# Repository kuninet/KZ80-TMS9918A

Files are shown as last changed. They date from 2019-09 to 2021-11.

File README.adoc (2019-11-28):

== KZ80シリーズ TMS9918A ビデオボード

=== 概要
* SBC8080バスにつながるTMS9918Aビデオボードのプロジェクトです。
* 本ボードの詳しい説明は以下のwikiページをご覧ください。
** https://github.com/kuninet/KZ80-TMS9918A/wiki

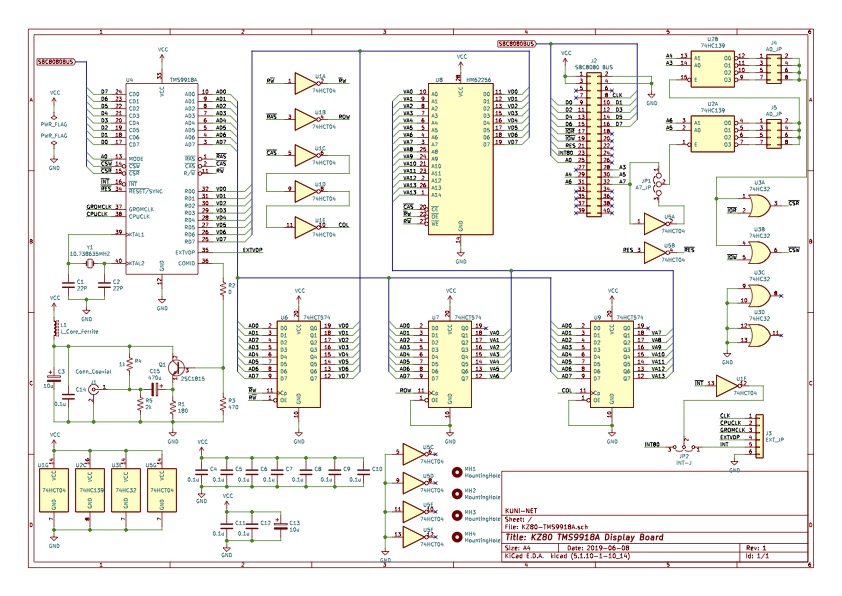
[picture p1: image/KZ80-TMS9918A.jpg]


=== ライセンス
* 本プロジェクトのデータはMITライセンスのもとで公開します。

=== 参考
* 以下のサイトの情報を参考に作成しています。ありがとうございます。
** https://github.com/jblang/TMS9918A
** https://retrobrewcomputers.org/n8vem-pbwiki-archive/0/35845334/48860720/33053543/SRAM%20Replacement%20for%20TMS99x8%20VRAM.pdf

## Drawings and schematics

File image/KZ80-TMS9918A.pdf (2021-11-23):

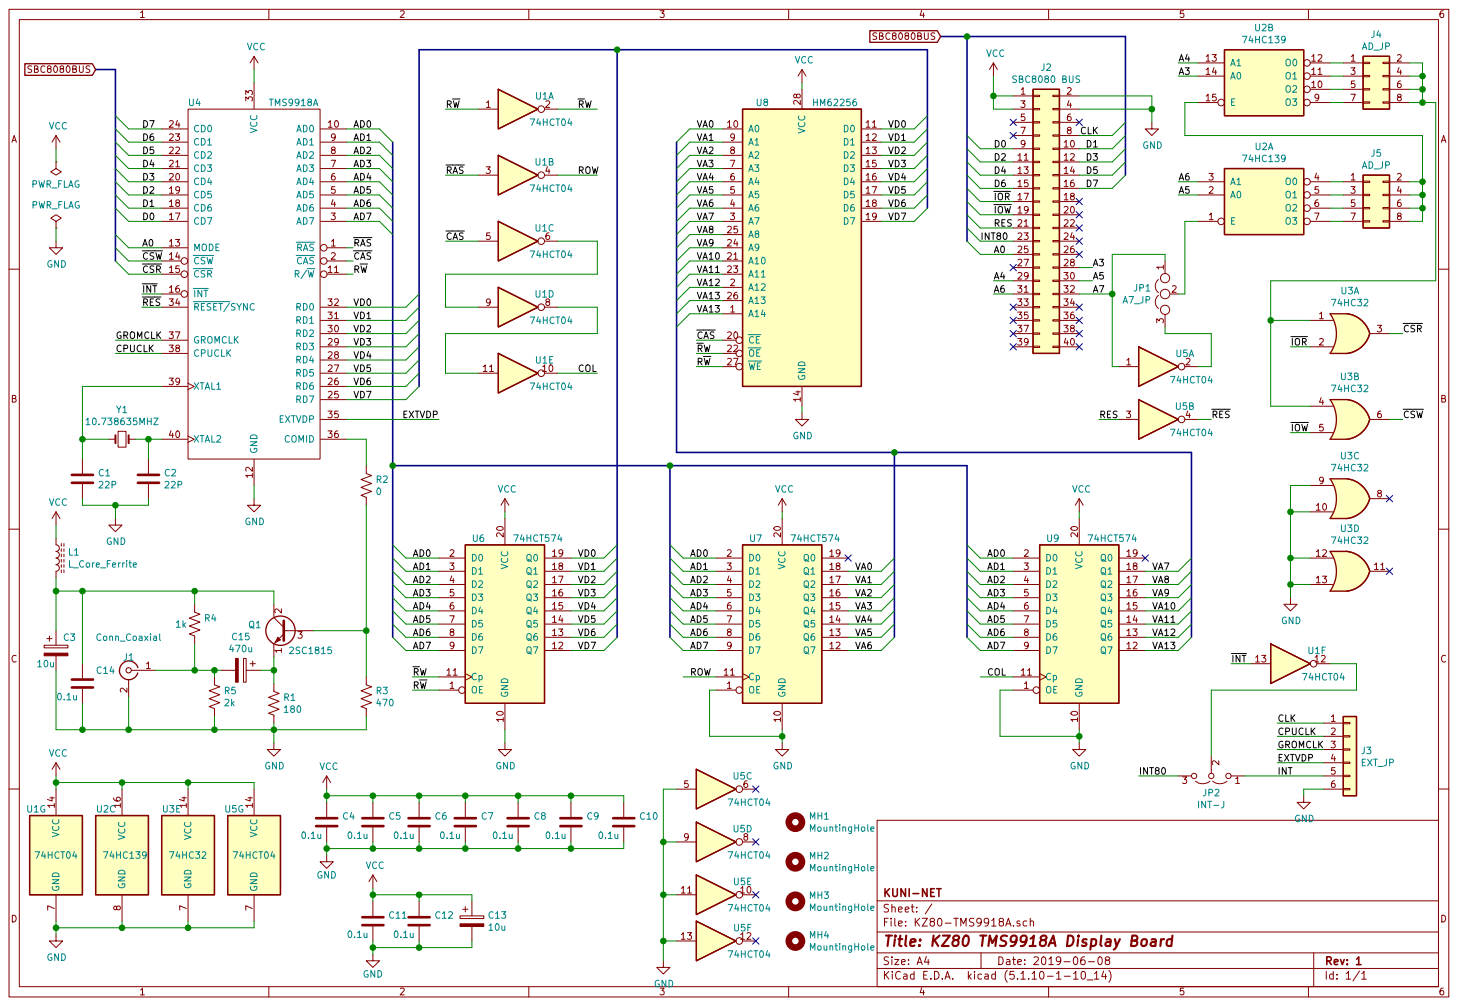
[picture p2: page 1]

74HCT04 MH4 MountingHole MH3 MountingHole MH2 MountingHole MH1 MountingHole C10

File: KZ80-TMS9918A.sch Sheet: / KUNI-NET

Id: 1/1 Title: KZ80 TMS9918A Display Board

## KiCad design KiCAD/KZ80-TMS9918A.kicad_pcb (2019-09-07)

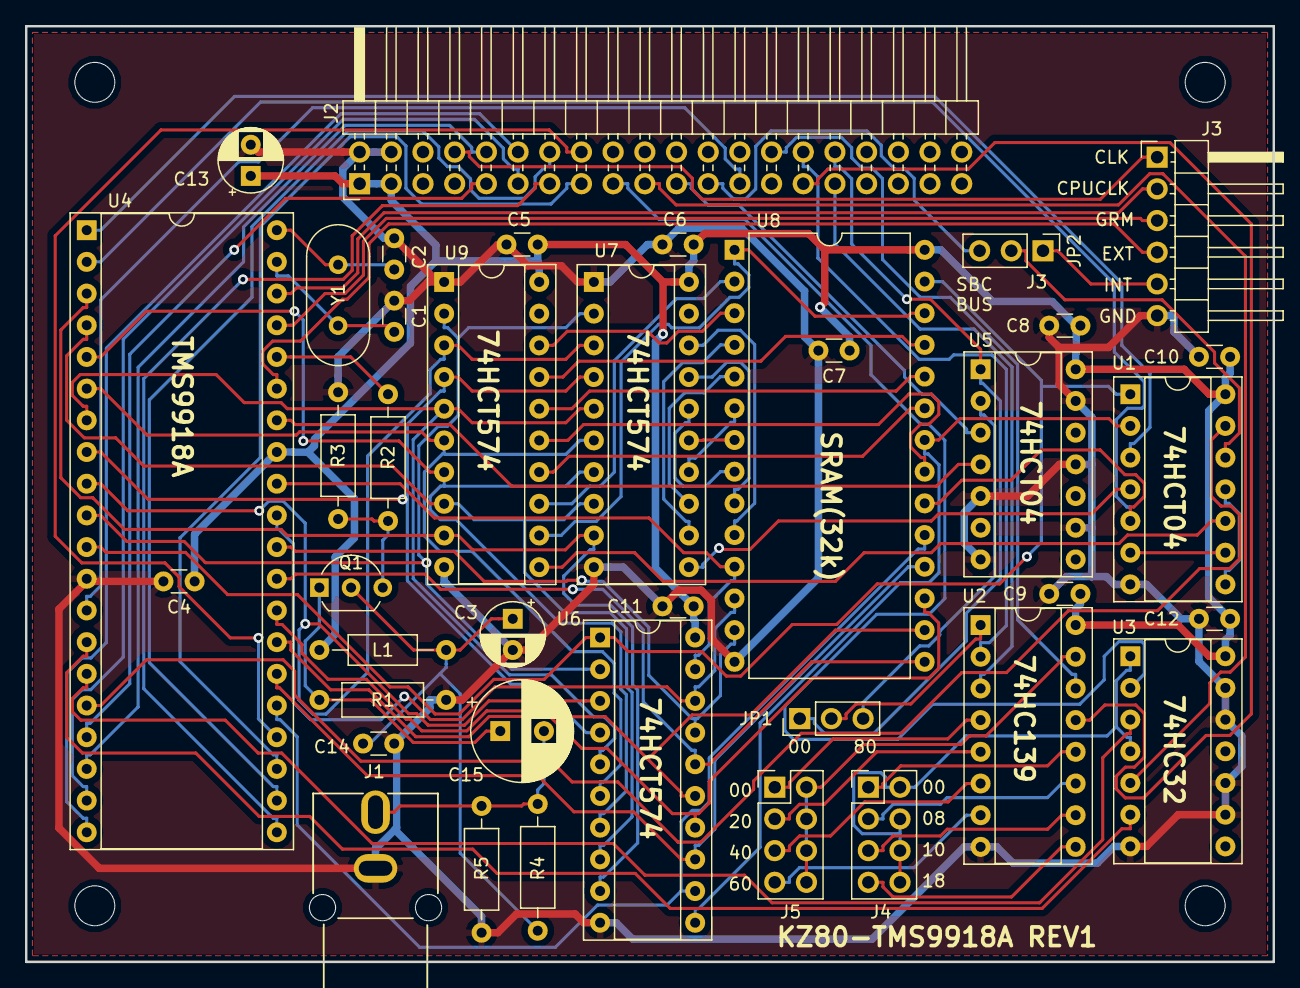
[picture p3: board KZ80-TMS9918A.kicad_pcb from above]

Board: 2 copper layers, 100.0 x 75.0 mm, 43 parts (0 on the bottom side), 87 nets.

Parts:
C1, C2: 22P; C_Disc_D3.0mm_W1.6mm_P2.50mm
C3, C13: 10u; CP_Radial_D5.0mm_P2.50mm
C4, C5, C6, C7, C8, C9, C10, C11, C12, C14: 0.1u; C_Disc_D3.0mm_W1.6mm_P2.50mm
C15: 470u; CP_Radial_D8.0mm_P3.50mm
J1: Conn_Coaxial; RCAConAE
J2: SBC8080 BUS; PinHeader_2x20_P2.54mm_Horizontal
J3: EXT_JP; PinHeader_1x06_P2.54mm_Horizontal
J4, J5: AD_JP; PinHeader_2x04_P2.54mm_Vertical
JP1: A7_JP; PinHeader_1x03_P2.54mm_Vertical
JP2: INT-J; PinHeader_1x03_P2.54mm_Vertical
L1: L_Core_Ferrite; L_Axial_L5.3mm_D2.2mm_P10.16mm_Horizontal_Vishay_IM-1
MH1, MH2, MH3, MH4: MountingHole; MountingHole_3.2mm_M3
Q1: 2SC1815; TO-92_Inline_Wide
R1: 180; R_Axial_DIN0207_L6.3mm_D2.5mm_P10.16mm_Horizontal
R2: 0; R_Axial_DIN0207_L6.3mm_D2.5mm_P10.16mm_Horizontal
R3: 470; R_Axial_DIN0207_L6.3mm_D2.5mm_P10.16mm_Horizontal
R4: 1k; R_Axial_DIN0207_L6.3mm_D2.5mm_P10.16mm_Horizontal
R5: 2k; R_Axial_DIN0207_L6.3mm_D2.5mm_P10.16mm_Horizontal
U1, U5: 74HCT04; DIP-14_W7.62mm_Socket
U2: 74HC139; DIP-16_W7.62mm_Socket
U3: 74HC32; DIP-14_W7.62mm_Socket
U4: TMS9918A; DIP-40_W15.24mm_Socket
U6, U7, U9: 74HCT574; DIP-20_W7.62mm_Socket
U8: HM62256; DIP-28_W15.24mm
Y1: 10.738635MHZ; Crystal_HC49-U_Vertical

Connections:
/A0: J2.25, U4.13
/A3: J2.28, U2.14
/A4: J2.29, U2.13
/A5: J2.30, U2.2
/A6: J2.31, U2.3
/A7: J2.32, JP1.1, U5.1
/AD0: U4.10, U6.2, U7.2, U9.2
/AD1: U4.9, U6.3, U7.3, U9.3
/AD2: U4.8, U6.4, U7.4, U9.4
/AD3: U4.7, U6.5, U7.5, U9.5
/AD4: U4.6, U6.6, U7.6, U9.6
/AD5: U4.5, U6.7, U7.7, U9.7
/AD6: U4.4, U6.8, U7.8, U9.8
/AD7: U4.3, U6.9, U7.9, U9.9
/CLK: J2.8, J3.1
/COL: U1.10, U9.11
/CPUCLK: J3.2, U4.38
/D0: J2.9, U4.17
/D1: J2.10, U4.18
/D2: J2.11, U4.19
/D3: J2.12, U4.20
/D4: J2.13, U4.21
/D5: J2.14, U4.22
/D6: J2.15, U4.23
/D7: J2.16, U4.24
/EXTVDP: J3.4, U4.35
/GROMCLK: J3.3, U4.37
/INT: J3.5, JP2.1
/INT80: J2.23, JP2.3
/RES: J2.21, U5.3
/ROW: U1.4, U7.11
/R~W: U1.1, U4.11, U6.1, U8.27
/VA0: U7.18, U8.10
/VA1: U7.17, U8.9
/VA2: U7.16, U8.8
/VA3: U7.15, U8.7
/VA4: U7.14, U8.6
/VA5: U7.13, U8.5
/VA6: U7.12, U8.4
/VA7: U8.3, U9.18
/VA8: U8.25, U9.17
/VA9: U8.24, U9.16
/VA10: U8.21, U9.15
/VA11: U8.23, U9.14
/VA12: U8.2, U9.13
/VA13: U8.1, U8.26, U9.12
/VD0: U4.32, U6.19, U8.11
/VD1: U4.31, U6.18, U8.12
/VD2: U4.30, U6.17, U8.13
/VD3: U4.29, U6.16, U8.15
/VD4: U4.28, U6.15, U8.16
/VD5: U4.27, U6.14, U8.17
/VD6: U4.26, U6.13, U8.18
/VD7: U4.25, U6.12, U8.19
/~CAS: U1.5, U4.2, U8.20
/~CSR: U3.3, U4.15
/~CSW: U3.6, U4.14
/~INT: U1.13, U4.16
/~IOR: J2.17, U3.2
/~IOW: J2.19, U3.5
/~RAS: U1.3, U4.1
/~RES: U4.34, U5.4
/~R~W: U1.2, U6.11, U8.22
GND: C1.2, C2.2, C3.2, C4.2, C5.2, C6.2, C7.2, C8.2, C9.2, C10.2, C11.2, C12.2, C13.2, C14.2, J1.2, J2.2, J2.4, J3.6, R1.2, R3.2, R5.2, U1.7, U2.8, U3.7, U3.9, U3.10, U3.12, U3.13, U4.12, U5.5, U5.7, U5.9, U5.11, U5.13, U6.10, U7.1, U7.10, U8.14, U9.1, U9.10
unnamed: C1.1, U4.39, Y1.1
unnamed: C2.1, U4.40, Y1.2
unnamed: C3.1, C14.1, L1.2, Q1.2, R4.1
unnamed: C15.1, Q1.1, R1.1
unnamed: C15.2, J1.1, R4.2, R5.1
unnamed: J4.1, U2.12
unnamed: J4.2, J4.4, J4.6, J4.8, U3.1, U3.4
unnamed: J4.3, U2.11
unnamed: J4.5, U2.10
unnamed: J4.7, U2.9
unnamed: J5.1, U2.4
unnamed: J5.2, J5.4, J5.6, J5.8, U2.15
unnamed: J5.3, U2.5
unnamed: J5.5, U2.6
unnamed: J5.7, U2.7
unnamed: JP1.2, U2.1
unnamed: JP1.3, U5.2
unnamed: JP2.2, U1.12
unnamed: Q1.3, R2.2, R3.1
unnamed: R2.1, U4.36
unnamed: U1.6, U1.9
unnamed: U1.8, U1.11
VCC: C4.1, C5.1, C6.1, C7.1, C8.1, C9.1, C10.1, C11.1, C12.1, C13.1, J2.1, J2.3, L1.1, U1.14, U2.16, U3.14, U4.33, U5.14, U6.20, U7.20, U8.28, U9.20

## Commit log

2019-06-11 init commit
    [KZ80-TMS9918A.dsn, KZ80-TMS9918A.kicad_pcb, KZ80-TMS9918A.sch]
2019-06-11 回路図イメージファイル追加
2019-07-15 RCAコネクタフットプリント作成。出力回路見直し
    [KZ80-TMS9918A.dsn, KZ80-TMS9918A.kicad_pcb, KZ80-TMS9918A.sch]
2019-07-15 改良版回路図再出力
2019-07-15 回路図表記間違い修正 74HC574→74HCT574
    [KZ80-TMS9918A.sch]
2019-07-15 ガーバーデータ出力
    [KZ80-TMS9918A.GBL, KZ80-TMS9918A.GBO, KZ80-TMS9918A.GBP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]
2019-07-16 パターンチェック後 SBCバスINT修正 、製造ファイル再出力
    [KZ80-TMS9918A.GBL, KZ80-TMS9918A.GBO, KZ80-TMS9918A.GBP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]
2019-07-16 回路図 修正版 再出力
2019-08-10 回路見直し&パターン再作成
    [KZ80-TMS9918A.GBL, KZ80-TMS9918A.GBO, KZ80-TMS9918A.GBP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]
2019-08-10 回路図イメージデータ最新化
2019-09-02 INT端子ジャンパ装備 パターン再作成、ガーバー出力
    [KZ80-TMS9918A.GBL, KZ80-TMS9918A.GBO, KZ80-TMS9918A.GBP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]
2019-09-07 ガーバーデータ出力設定見直し。プロットし直し
    [KZ80-TMS9918A.GBL, KZ80-TMS9918A.GBO, KZ80-TMS9918A.GBP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]
2021-11-23 回路図イメージ差し替え
